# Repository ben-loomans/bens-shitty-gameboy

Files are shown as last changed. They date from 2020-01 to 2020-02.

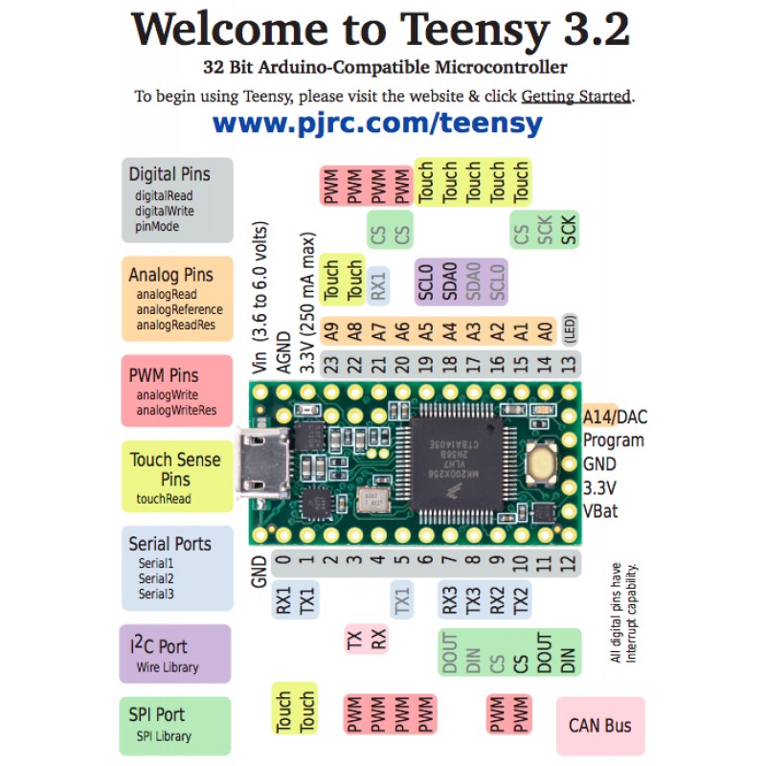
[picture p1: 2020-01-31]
resources/Teensy 3.2.jpg

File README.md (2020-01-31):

# bens-shitty-gameboy
Just like it says on the box: a pretty shitty "gameboy" that I learned a lot from making.

I made this repository after already finishing a working version of the BSG (Ben's Shitty "Gameboy"), because I think knowing how to use git and Github is valuable knowledge and learning within a context is far more effective than without.

Basic list of features (and their implementation status):
1.	6 hardware-debounced buttons (4 in a D-Pad arrangement + A & B)		Done
2.	A 128x64 LCD Screen													Done
3.	Light Dependent Resistor (LDR)										Done
4.	38kHz Infrared receiver												Done
5.	Infrared transmitter												Not Done
6.	Capacitive button													Not Done

Planned features will be added to a TODO document rather than here I think.

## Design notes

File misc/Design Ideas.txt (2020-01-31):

Ideas:

Capacitive touch sensing:
https://www.youtube.com/watch?v=mWR9Q_pTagw

Direct board interaction (touching traces, running fingers along, etc.)

Interesting sensing capability (light, temperature)

Accelerometer

piezo sound (midi?)

3D printed enclosure - captive nut M4 ~20mm hex socket head screws

traditional gameboy golden ratio box?

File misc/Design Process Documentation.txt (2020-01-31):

I was thinking to myself while riding to work this morning that it might be useful to have a document detailing how I went about this project. Some of this will be written retrospectively, but hopefully most of it will be written as I go. I still have some anxieties about not actually completing this, as I often have big ideas but never really put in the work required to bring them into reality. I've already put in some of the boring work required to bring this shitty gameboy into the world, so that's at least a headstart over most of my other projects.

I had the idea to make this after doing CAB202 last year, where we programmed a teensy-based handheld game console with a screen resolution of 84x48 from memory, which struck me as a strange number. The LCD I have purchased is 128x64, which will hopefully alleviate some of the frustrations I had with the resolution of the CAB202 design. I've also purchased a teensy 3.2, which uses an ARM-based microprocessor rather than an 8-bit RISC which I think is what we were using last time. Making that amplifier for Matt at Ionode gave me the necessary skills in Eagle to create a custom PCB, and there are many very cheap PCB manufacturing services on the internet too. 

I was just thinking about how I would go about making more of these if I wanted to give some out, and it rustled my jimmies how expensive the LCD was, so I researched new sources. Turns out I can get an LCD of the same resolution as mine for less than 10 bucks. I'll have to look into it.

Another issue is that it costs $11 + shipping to get 5 boards with a nice 80x130mm ratio, but if I cut off those 30mm I can get it for $3. 

I think I just need to suck it up and make a (really) shitty prototype, and go from there. I've been stressing about whether to put fancy piezo drivers and capacitive buttons on but I really just need to start simple I think. Push-buttons, maybe a piezo that makes simple tones, and an infrared LED just for fun.

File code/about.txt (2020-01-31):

In order to compile this code, the Arduino IDE and Teensy Add-On is required
The code is written for a Teensy 3.2

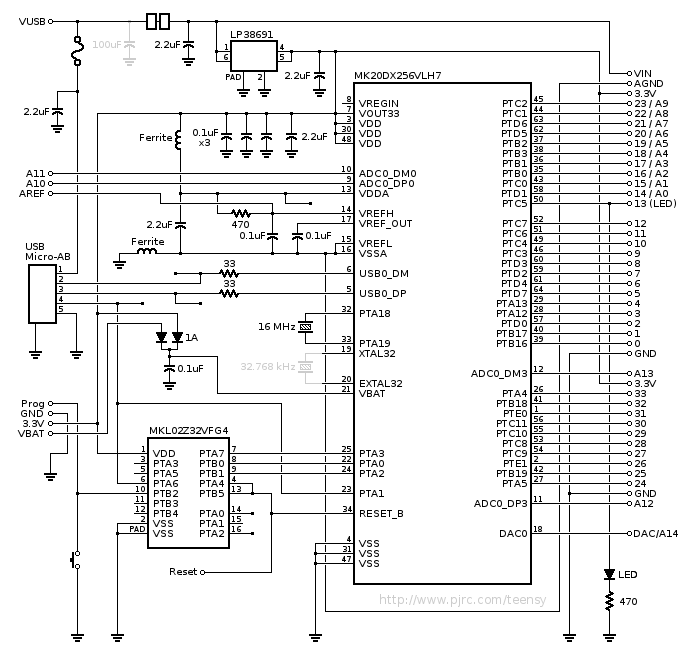
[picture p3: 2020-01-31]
resources/Teensy 3.2 Diagram.png

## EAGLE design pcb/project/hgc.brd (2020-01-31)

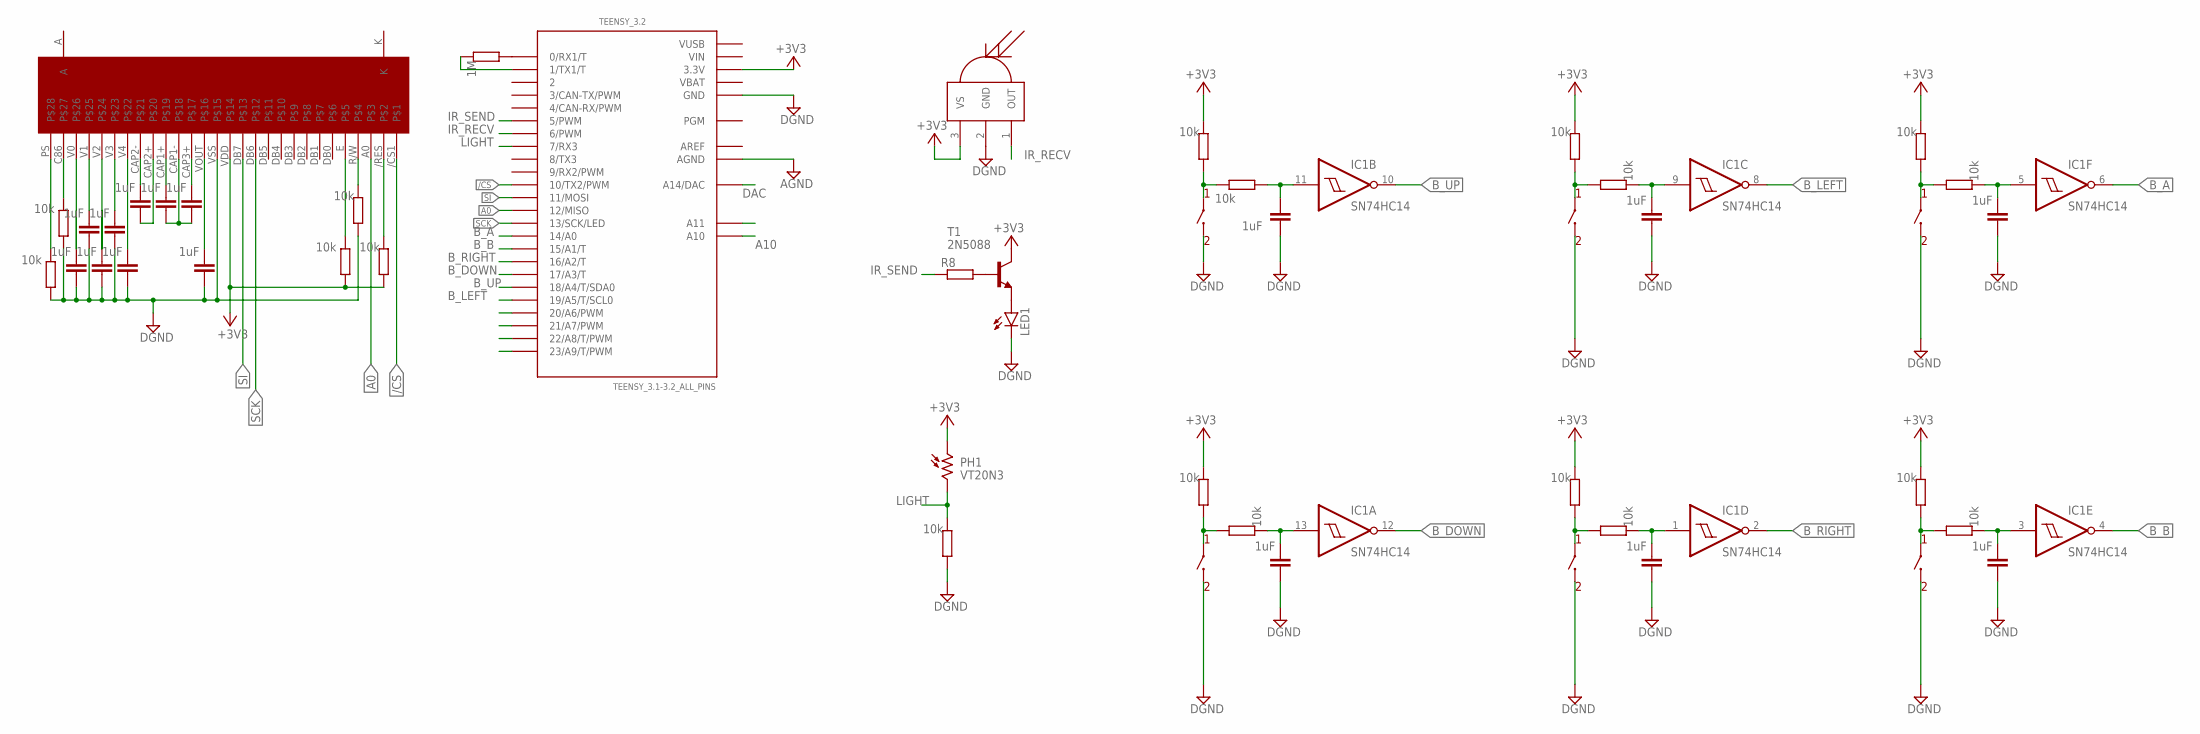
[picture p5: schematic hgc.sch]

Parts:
A: TACTILE_SWITCH; SPST-NO
B: TACTILE_SWITCH; SPST-NO
C1, C2, C3, C4, C5, C6, C7, C8, C9, C10, C11, C12, C13, C14, C15: 1uF; C0603
DOWN: TACTILE_SWITCH; SPST-NO
IC1: SN74HC14; SO14
LED1: LED3MM
LEFT: TACTILE_SWITCH; SPST-NO
PH1: VT20N3; TO46-VT200
R1, R2, R3, R4, R5, R6, R7, R9, R10, R11, R12, R13, R15, R16, R18, R19, R21, R22: 10k; R0603
R8: R-EU_0204/7; 0204/7
R14: 1M; R0603
RIGHT: TACTILE_SWITCH; SPST-NO
T1: 2N5088; TO92
TEENSY_3.2: TEENSY_3.1-3.2_ALL_PINS; TEENSY_3.0-3.2&LC_ALL_PINS
U$2: LCD_DISPLAY; LCD_SCREEN
U$3: IR_RECEIVER; T-30_V
UP: TACTILE_SWITCH; SPST-NO

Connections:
20: TEENSY_3.2.20/A6 (20/A6/PWM)
21: TEENSY_3.2.21/A7 (21/A7/PWM)
22: TEENSY_3.2.22/A8 (22/A8/T/PWM)
23: TEENSY_3.2.23/A9 (23/A9/T/PWM)
/CS: TEENSY_3.2.10 (10/TX2/PWM), U$2./CS1
/WRITE: R2.1, U$2.R/W
A: U$2.A
A0: TEENSY_3.2.12 (12/MISO), U$2.A0
A10: TEENSY_3.2.A10
A11: TEENSY_3.2.A11
AGND: TEENSY_3.2.AGND
AREF: TEENSY_3.2.AREF
B_A: IC1.6 (O), TEENSY_3.2.14/A0
B_B: IC1.4 (O), TEENSY_3.2.15/A1 (15/A1/T)
B_DOWN: IC1.12 (O), TEENSY_3.2.17/A3 (17/A3/T)
B_LEFT: IC1.8 (O), TEENSY_3.2.19/A5 (19/A5/T/SCL0)
B_RIGHT: IC1.2 (O), TEENSY_3.2.16/A2 (16/A2/T)
B_UP: IC1.10 (O), TEENSY_3.2.18/A4 (18/A4/T/SDA0)
DAC: TEENSY_3.2.RESET/DAC (A14/DAC)
DGND: A.3 (2), A.4 (2), B.3 (2), B.4 (2), C1.2, C2.2, C3.2, C4.2, C5.2, C9.2, C10.2, C11.2, C12.2, C13.2, C14.2, C15.2, DOWN.3 (2), DOWN.4 (2), IC1.7 (GND), LED1.K (C), LEFT.3 (2), LEFT.4 (2), R2.2, R4.1, R5.1, R11.2, RIGHT.3 (2), RIGHT.4 (2), TEENSY_3.2.GND, TEENSY_3.2.GND1 (GND), U$2.VSS, U$3.2 (GND), UP.3 (2), UP.4 (2)
ENABLE: R1.2, U$2.E
IR_RECV: TEENSY_3.2.6 (6/PWM), U$3.1 (OUT)
IR_SEND: R8.1, TEENSY_3.2.5 (5/PWM)
K: U$2.K
LIGHT: PH1.2, R11.1, TEENSY_3.2.7 (7/RX3)
unnamed: C1.1, U$2.V0
unnamed: C2.1, U$2.V1
unnamed: C3.1, U$2.V2
unnamed: C4.1, U$2.V3
unnamed: C5.1, U$2.V4
unnamed: C6.1, U$2.CAP2-
unnamed: C7.1, U$2.CAP1+
unnamed: C8.1, U$2.CAP3+
unnamed: C9.1, U$2.VOUT
unnamed: R3.1, U$2./RES
unnamed: C6.2, U$2.CAP2+
unnamed: C7.2, C8.2, U$2.CAP1-
unnamed: R4.2, U$2.PS
unnamed: R5.2, U$2.C86
unnamed: LED1.A, T1.3 (E)
unnamed: R6.2, R7.2, UP.1, UP.2 (1)
unnamed: C10.1, IC1.11 (I), R7.1
unnamed: LEFT.1, LEFT.2 (1), R9.2, R10.2
unnamed: R8.2, T1.2 (B)
unnamed: C11.1, IC1.9 (I), R10.1
unnamed: A.1, A.2 (1), R12.2, R13.2
unnamed: C12.1, IC1.5 (I), R13.1
unnamed: DOWN.1, DOWN.2 (1), R15.2, R16.2
unnamed: R14.2, TEENSY_3.2.0 (0/RX1/T)
unnamed: C13.1, IC1.13 (I), R16.1
unnamed: R18.2, R19.2, RIGHT.1, RIGHT.2 (1)
unnamed: R14.1, TEENSY_3.2.1 (1/TX1/T)
unnamed: C14.1, IC1.1 (I), R19.1
unnamed: B.1, B.2 (1), R21.2, R22.2
unnamed: C15.1, IC1.3 (I), R22.1
SCK: TEENSY_3.2.13 (13/SCK/LED), U$2.DB6
SI: TEENSY_3.2.11 (11/MOSI), U$2.DB7
VBAT: TEENSY_3.2.VBAT
VCC: IC1.14 (VCC), PH1.1, R1.1, R3.2, R6.1, R9.1, R12.1, R15.1, R18.1, R21.1, T1.1 (C), TEENSY_3.2.3.3V, TEENSY_3.2.3.3V1 (3.3V), U$2.VDD, U$3.3 (VS)
VIN: TEENSY_3.2.VIN
VUSB: TEENSY_3.2.VUSB

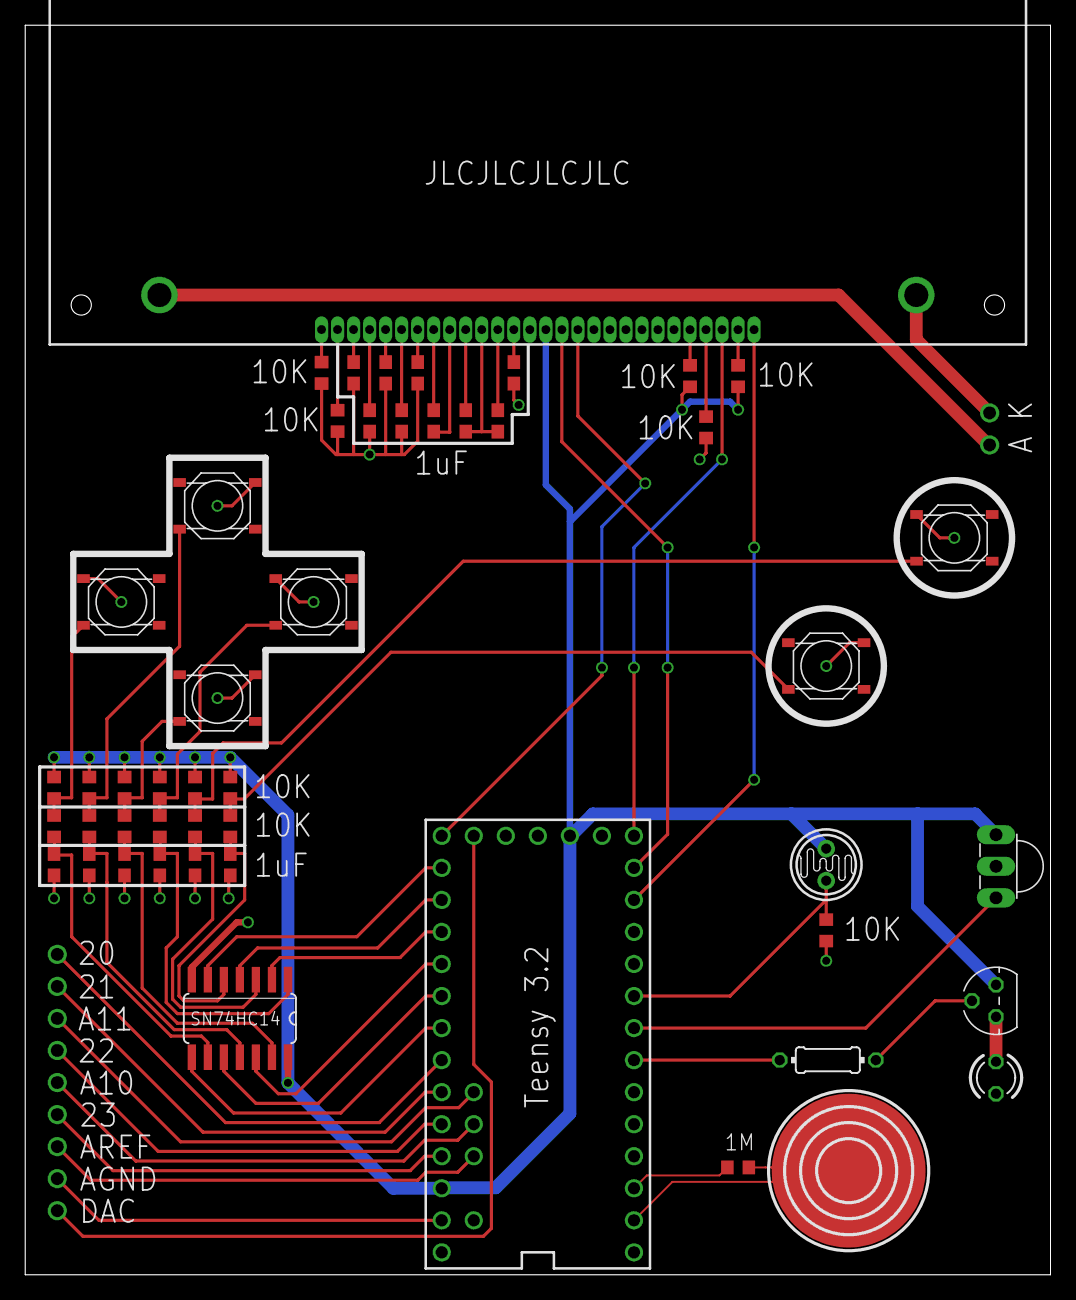
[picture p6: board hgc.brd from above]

Board: 2 copper layers, 81.3 x 99.1 mm, 48 parts (0 on the bottom side), 47 nets.

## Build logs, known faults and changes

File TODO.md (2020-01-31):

This file will contain some ideas I have for future versions of this project, regardless of how strongly I intend to implement them.

* Battery power - having a laptop attached to the BSG isn't ideal
* Case - 3D printed case with buttons and possibly a screen protector
* Speaker
* SD cartridge - load games from an SD card
* Colour display - issues associated with cost however
* Buttons with more travel

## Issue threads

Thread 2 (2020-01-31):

LDR pin mistake

ben-loomans, 2020-01-31:
In the Eagle project files, the LDR voltage divider is connected to a digital pin rather than an analog one. Not good unless I use it solely as a button.

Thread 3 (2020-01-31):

Reset pin LCD

ben-loomans, 2020-01-31:
The reset pin on the LCD is tied high, but in the sample initialisation code it seems like a reset is necessary.

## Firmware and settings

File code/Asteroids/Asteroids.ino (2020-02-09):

#include "asteroid_functions.h"
 
void setup() {
  Serial.begin(9600);

  randomSeed(analogRead(21));

  //init_buttons();
  init_lcd();
  asteroidb.set_speed(-2, 1);
  ship.set_speed(0, -4);
}

void loop() {
  clear_buffer();
  asteroidb.draw();
  ship.draw();
  //asteroidb.draw();
  asteroidb.update();
  ship.update();
  update_screen(frame_buffer);
  delay(200);
}

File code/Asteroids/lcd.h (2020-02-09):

  #include "lcd_commands.h"

#define SCREEN_WIDTH  128
#define SCREEN_HEIGHT 64

//uint8_t screen_buffer[SCREEN_WIDTH * SCREEN_HEIGHT / 8];
 

#define LCD_H
#define CS_PIN    10
#define SI_PIN    11
#define A0_PIN    12
#define SCL_PIN   13
#define RESET_PIN 21


#define SCL_LOW digitalWrite(13, 0)
#define SCL_HIGH digitalWrite(13, 1)

#define A0_COMM digitalWrite(12, 0)
#define A0_DATA digitalWrite(12, 1)

#define SI_LOW digitalWrite(11, 0)
#define SI_HIGH digitalWrite(11, 1)

#define CS_LOW digitalWrite(10, 0)
#define CS_HIGH digitalWrite(10, 1)

#define RESET_LOW digitalWrite(21, 0)
#define RESET_HIGH digitalWrite(21, 1)

#define DELAY delayMicroseconds(1)


void init_pins() {
  
  pinMode(CS_PIN, OUTPUT);
  pinMode(SI_PIN, OUTPUT);
  pinMode(A0_PIN, OUTPUT);
  pinMode(SCL_PIN, OUTPUT);
  pinMode(RESET_PIN, OUTPUT);
  
}

void out(uint8_t data) {
  for (int i = 0; i < 8; i++) {

    SCL_LOW;
    DELAY;
    
    if ((data & (0x80 >> i))) {
      SI_HIGH;
      //Serial.print("1");
    } else {
      SI_LOW;
      //Serial.print("0");
    }
    DELAY;
    
    SCL_HIGH;
    DELAY;
    
  }
}

void send_command(uint8_t data) {
  CS_LOW;
  A0_COMM;
  DELAY;
  
  out(data);
  
  CS_HIGH;
  DELAY;
}

void send_data(uint8_t data) {
  CS_LOW;
  A0_DATA;
  DELAY;
  
  out(data);
  
  CS_HIGH;
  //Serial.println(data, HEX);
  DELAY;
}

void init_lcd() {
  init_pins();
  
  CS_LOW;
  RESET_HIGH;
  RESET_LOW;
  delay(100);
  RESET_HIGH;
  delay(100);

  send_command(INTERNAL_RESET);
  delay(10);
  send_command(LCD_BIAS_NINTH);
  delay(10);
  send_command(COM_OUTPUT_REV);
  delay(10);
  send_command(SET_STARTLINE | 0);
  delay(10);
  send_command(RESISTOR_RATIO | 5);
  delay(10);
  send_command(ELEC_VOL_MODE);
  delay(10);
  send_command(ELEC_VOL_SET | 16);
  delay(10);
  send_command(POWER_MODE_SET | 7);
  delay(10);
  send_command(DISPLAY_ON);
  delay(10);
  send_command(DISPLAY_ALL_ON);
  delay(1000);
  send_command(DISPLAY_ALL_OFF);
}

void update_screen(uint8_t frame_buffer[][SCREEN_WIDTH]) {
  //send_command(DISPLAY_OFF);
  
  for (int page = 0; page < SCREEN_HEIGHT/8; page++) {
    
    send_command(SET_PAGE_ADDR | page);
    send_command(UPPER_COL_ADDR | 0);
    send_command(LOWER_COL_ADDR | 0);
    
    for (int column = 0; column < SCREEN_WIDTH; column++) {
      
      send_data(frame_buffer[page][column]);
      
    }
  }
  
  //send_command(DISPLAY_ON);
}

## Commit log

2020-01-31 Add Arduino code
2020-01-31 Add pcb-related files
    [hgc.brd, hgc.sch]
2020-02-09 change char to uint8_t and add rudimentary button function stack
